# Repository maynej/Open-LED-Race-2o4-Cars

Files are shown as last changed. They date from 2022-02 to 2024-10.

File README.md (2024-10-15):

# OpenLEDrace-2-4-Cars

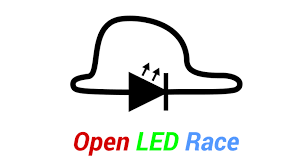
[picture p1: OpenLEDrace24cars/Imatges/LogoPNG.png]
Capses per control, Loop i Bridge per Open LED Race 

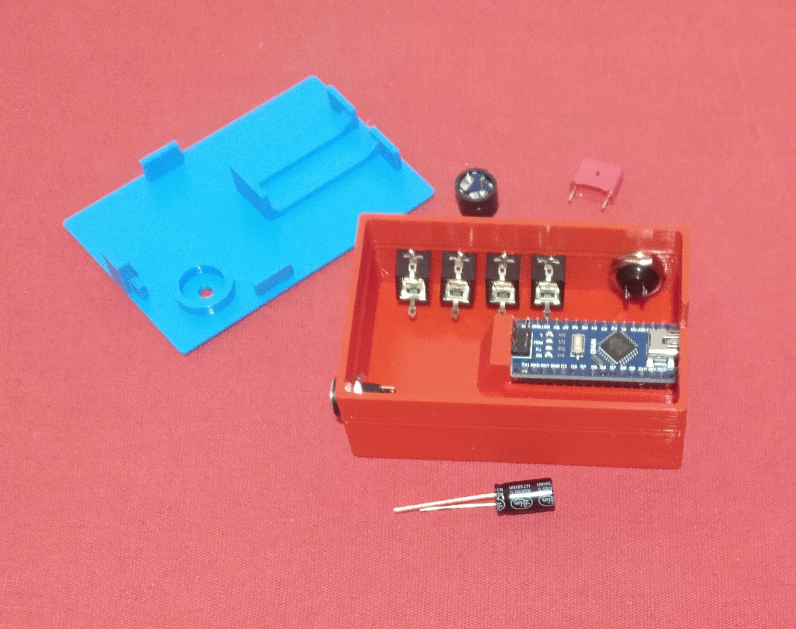
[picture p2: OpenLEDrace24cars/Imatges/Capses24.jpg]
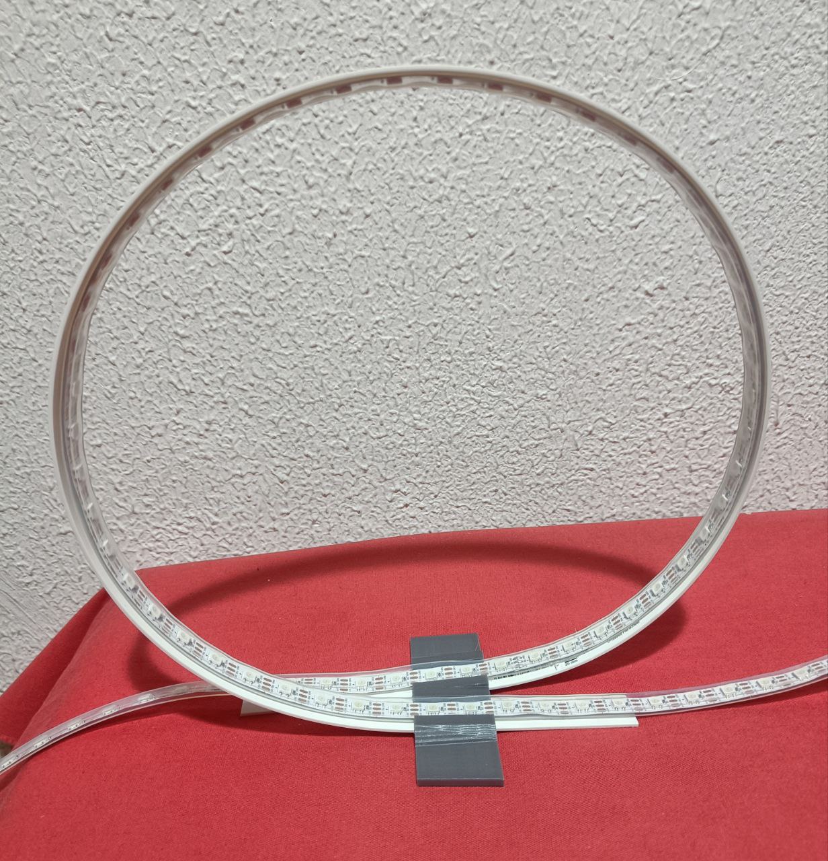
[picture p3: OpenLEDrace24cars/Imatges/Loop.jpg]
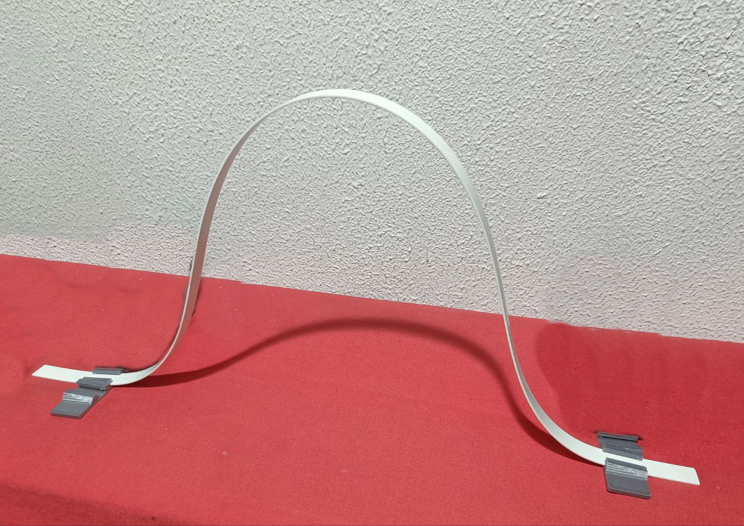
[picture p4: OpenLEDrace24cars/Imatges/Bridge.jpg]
     

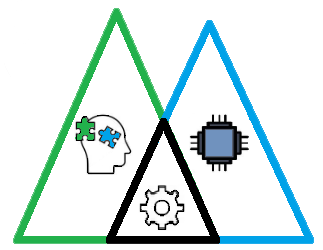
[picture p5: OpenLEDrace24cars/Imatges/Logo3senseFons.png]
Realitzada per [Jordi Mayné](https://github.com/maynej) des de Mechatronic Study 

Web Open LED Race: http://openledrace.net 

L'objectiu es tenir unes capses lleugeres per incloure la placa de control Arduino i el connexionat. També un suport per el Loop.

La [documentació es pot trobar en PDF](https://github.com/maynej/OpenLEDrace24cars/tree/main/OpenLEDrace24cars/DOC). També en llengua castellana.

El Firmware utilitzat [es pot trobar a](https://github.com/maynej/OpenLEDrace24cars/tree/main/OpenLEDrace24cars/Firmware). 

STL per imprimir [aquí](https://github.com/maynej/OpenLEDrace24cars/tree/main/OpenLEDrace24cars/STL).

## Capses 3D 
  
Descripció         | Imatge          | Arxius STL         
------------- | ------------- | ------------- 
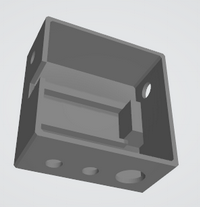
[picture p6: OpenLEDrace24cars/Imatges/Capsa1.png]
Capsa 2/4 jugadors | | [Capsa 2/4 jugadors](OpenLEDrace24cars/STL/CapsaArduinoOpenLedRaceV1.stl)
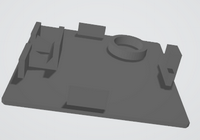
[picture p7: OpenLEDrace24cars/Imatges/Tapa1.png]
Tapa 2/4 jugadors | | [Tapa 2/4 jugadors](OpenLEDrace24cars/STL/TapaArduinoOpenLedRaceV1.stl)
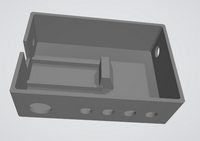
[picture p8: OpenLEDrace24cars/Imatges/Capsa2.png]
Capsa 4 jugadors | | [Capsa 4 jugadors](OpenLEDrace24cars/STL/Capsa_ArduinoGran4Players.stl)
Tapa 4 jugadors | | [Tapa 4 jugadors](OpenLEDrace24cars/STL/TapaArduino4Players.stl)

## Loops & bridges  
  
Descripció         | Imatge          | Arxius STL         
------------- | ------------- | ------------- 
Suport Loop | | [Suport Loop](OpenLEDrace24cars/STL/SuportLoopOLR.stl)
Suport Bridge 1 | | [Suport Bridge 1](OpenLEDrace24cars/STL/SuportBridgeOLR1.stl)
Suport Bridge 2 | | [Suport Bridge 2](OpenLEDrace24cars/STL/SuportBridgeOLR2.stl)

## Polsadors 3D
Descripció         | Imatge          | Arxiu STL          
------------- | ------------- | ------------- 
Polsador ergonomic | | [Polsador ergonomic](OpenLEDrace24cars/STL/OpenLedRace_Handle.stl)

## QR


## Llicència

Creative Commons Attribution-NoComercial-ShareAlike 4.0 International (CC BY-NC-SA 4.0)

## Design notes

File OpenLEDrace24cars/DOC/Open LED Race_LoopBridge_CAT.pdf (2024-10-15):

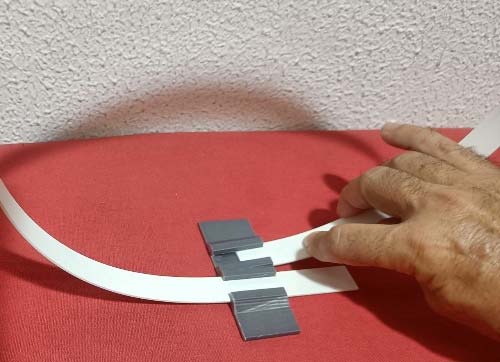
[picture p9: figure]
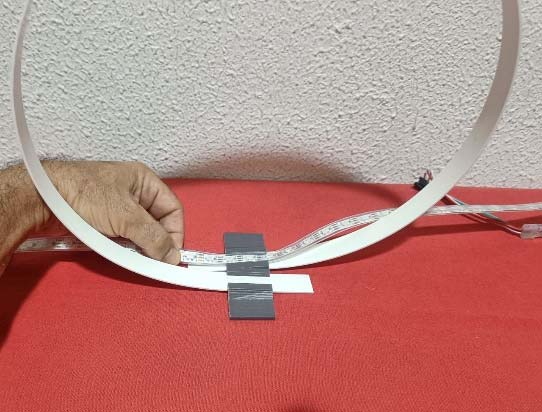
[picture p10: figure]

1

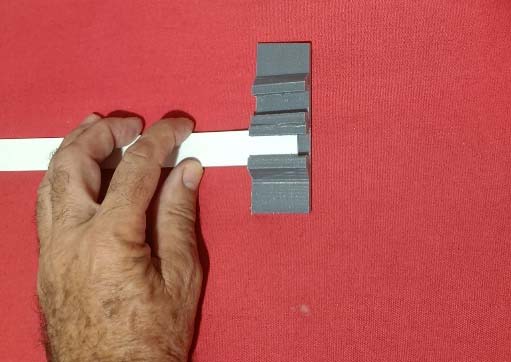
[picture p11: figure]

Jordi Mayné 2024

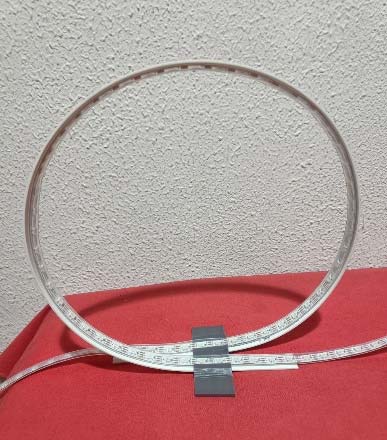
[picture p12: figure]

## Construcció del Loop per Open LED Race

Una de les parts més curioses del joc Open LED Race és la construcció d'un Loop, on depenent del microprogramari hi ha la possibilitat de que el jugador comprovi la força de la gravetat, si el vehicle no porta una velocitat suficient no podrà passar el Loop. Haurà de deixar caure enrere per tornar a agafar l'acceleració necessària per passar aquest Loop.

La dificultat d´aquesta construcció s´ha resolt molt fàcilment amb una platina de PVC i peça impresa en 3D..

Material i montatge:

- 1 Platina de PVC blanc de 20 x 2 x 1000 mm
- 1 Suport de platina i Neopixel

Una vegada imprès el suport s'insereix la platina a través de la ranura i es deixa sortir per l'altra banda, després s'insereix l'altra punta de la platina pel costat contrari i el Loop s'aguantarà ben estable. Depenent de la inserció pot quedar més petit o més gran (uns 25 cm de diàmetre).

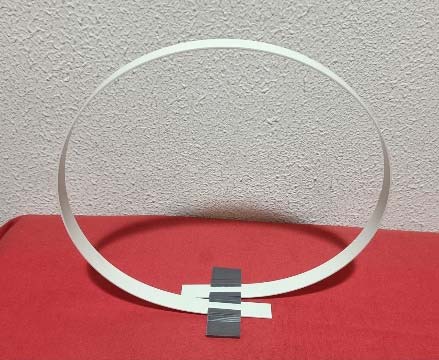
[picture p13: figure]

Ara es prepara la tira de LED Neopixel i es posa en el punt adequat (amb els llums actius de posicionament en la part més alta del Loop), la ranura per la tira Neopixel està molt justa perquè es retingui i no cal posar cap cinta adhesiva, s'aguantará sense cap problema.

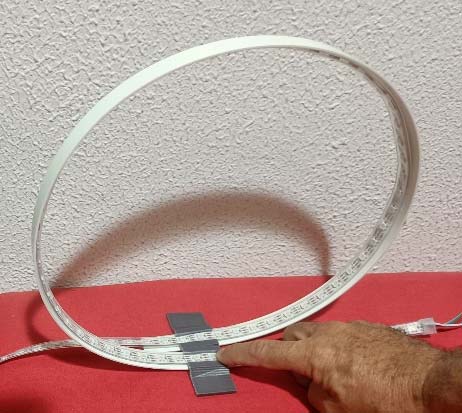
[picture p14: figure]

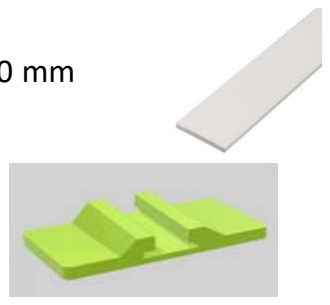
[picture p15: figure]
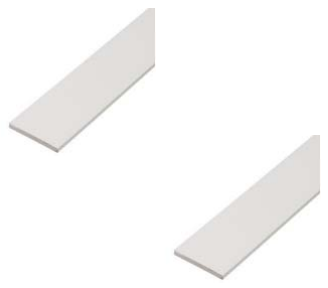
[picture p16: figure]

2
Jordi Mayné 2024

## Construcció del Bridge per Open LED Race

Una alternativa al Loop pot ser un Bridge. Però, també es pot posar en qualsevol part del circuit com un pont.

Aprofitant el disseny de la peça per fer el Loop i fent una mica de modificació s´ha resolt de dues maneres.

Material i muntatge:

- 1 Platina de PVC blanc de 20 x 2 x 1000 mm
- 1 Suport de platina i Neopixel

Aquest muntatge cal afegir cinta adhesiva en el suport.

L’altre solució es amb el suport següent que necessita a més una platina d’alumini de 2 x 20 x L, on L es la longitud, crec que pot anar bé des de 50 cm fins 100 cm segons agradi.

Material i muntatge:

- 1 Platina de PVC blanc de 20 x 2 x 1000 mm
- 1 Platina d’alumini de 20 x 2 x L mm
- 1 Suport de platina i Neopixel

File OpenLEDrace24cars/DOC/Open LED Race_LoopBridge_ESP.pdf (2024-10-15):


1


Jordi Mayné 2024


## Construcción del Loop para Open LED Race

Una de las partes más curiosas del juego Open LED Race es la construcción de un Loop donde dependiendo del firmware hay la posibilidad de que el jugador compruebe la fuerza de la gravedad, si el vehículo no lleva una velocidad adecuada no podrá pasar el Loop. Tendrá que dejar caer hacia atrás para volver a coger la aceleración necesaria para pasar dicho Loop.

La dificultad de esta construcción se ha resuelto muy fácilmente con una pletina de PVC y pieza impresa en 3D.

Material y montaje:

- 1 Pletina de PVC blanco de 20 x 2 x 1000 mm
- 1 Soporte de pletina y Neopixel

Una vez impreso el soporte se inserta la pletina a través de la ranura y se deja salir por el otro lado, después se inserta la otra punta de la pletina por el lado contrario y el Loop se aguantará bien estable. Dependiendo de la inserción puede quedar más pequeño o más grande (unos 25 cm de diámetro).


Ahora se prepara la tira de LED Neopixel y se pone en el punto adecuado (con las luces activas de posicionamiento en la parte más alta del Loop), la ranura para Neopixel está muy justa para que se retenga y no hace falta poner ninguna cinta adhesiva, se aguantará sin ningún problema.


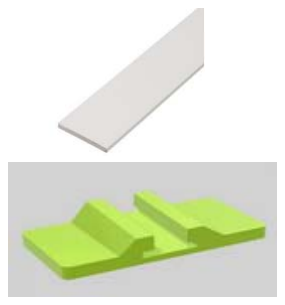
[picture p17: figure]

2
Jordi Mayné 2024

## Construcción del Bridge para Open LED Race

Una alternativa al Loop puede ser un Bridge. Pero también se puede poner en cualquier parte del circuito como un puente.

Aprovechando el diseño de la pieza para hacer el Loop y haciendo una pequeña modificación se ha resuelto de dos maneras.

Material y montaje:

- 1 Pletina de PVC blanco de 20 x 2 x 1000 mm
- 2 Soportes iguales para pletina y Neopixel

Este montaje necesita añadir una cinta adhesiva en el soporte.

Otra solución es con el soporte siguiente, que necesita además una pletina de aluminio de 2 x 20 x L, donde L es la longitud, creo que puede ir bien desde 50 cm hasta 100 cm según agrade.

Material y montaje:

- 1 Pletina de PVC blanco de 20 x 2 x 1000 mm
- 1 Pletina de aluminio de 20 x 2 x L
- 2 Soportes iguales para pletina y Neopixel

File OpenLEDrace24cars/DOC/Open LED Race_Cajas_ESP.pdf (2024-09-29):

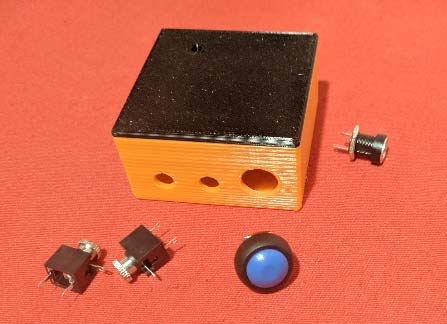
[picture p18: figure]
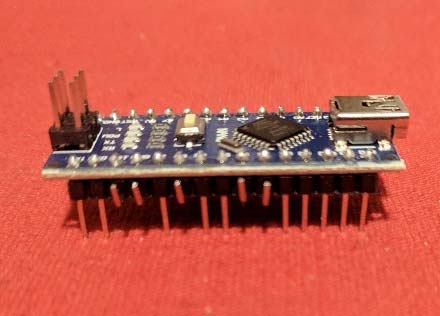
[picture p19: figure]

Jordi Mayné 2020

## Open LED Race 2 jugadores caja pequeña

Material y montaje del Arduino:

- STL de https://www.thingiverse.com/thing:4082216
- 2 jacks hembra 3,5mm PJ-301M
- 1 Pulsador PBS-33b 12mm
- 1 Conector de alimentación hembra de 7,8mm de diámetro
- 1 Condensador electrolítico 1000uF/6V3
- 1 Resistencia entre 330 y 500 ohm
- 1 Zumbador 12 mm
- 1 Condensador 1uF cerámico
- 1 Arduino Nano
- 1 Cable con conector JST de 3 pines macho

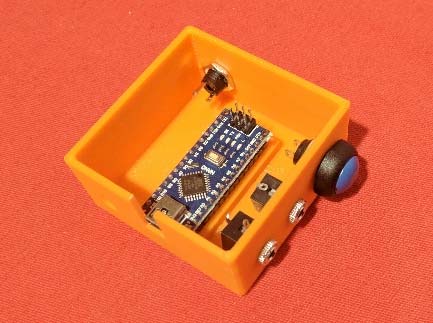
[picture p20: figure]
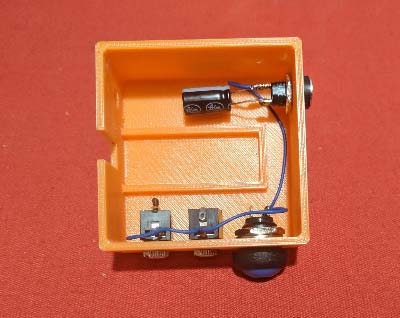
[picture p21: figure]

Una vez montados los conectores y el pulsador, hace falta preparar la placa Arduino. Todos los pines que se han de utilizar hace falta doblar hacia arriba, tal como se muestra en la primera imagen utilizando unos alicates de punta fina, después se estañan, tal como se muestra la segunda imagen y después se sueldan los cables y la resistencia.

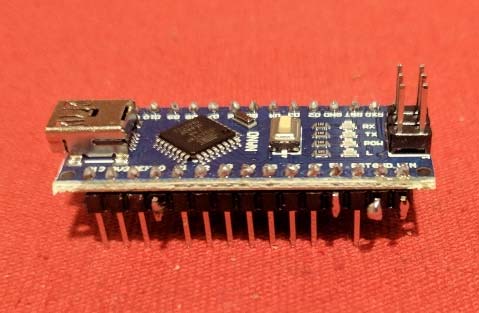
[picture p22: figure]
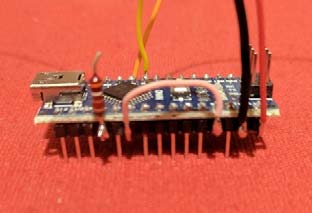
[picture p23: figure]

Se coloca la placa Arduino Nano en el encaje de la caja y se sueldan los hilos a los conectores, y el resto de componentes. Pero se ha de mirar el firmware que se quiere utilizar para mirar la configuración de los pines.

En este caso se ha de utilizar:

- PIN_LED | A0 a R 470 ohms hacia el pin DIN de la tira Neopixel WS2812b
- PIN_P1 | D7 al conector del jugador 1
- PIN_P2 | D6 al conector del jugador 2
- PIN_AUDIO D3 al condensador de 1uF hacia el zumbador
- Alimentación VIN a +5V GND a massa
- Puente entre A2 y 5V
- RST al pulsador de Reset

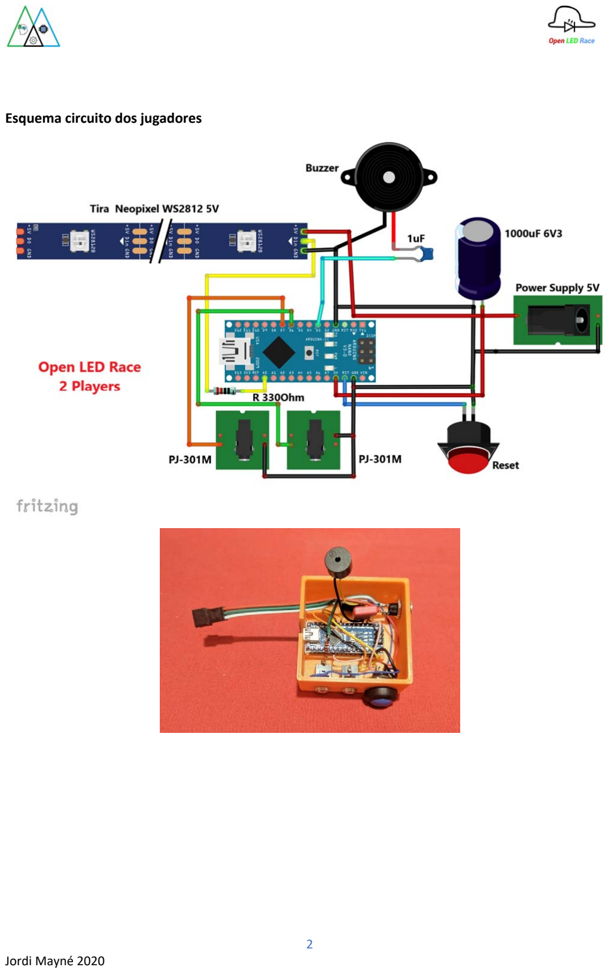
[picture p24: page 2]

Esquema circuito dos jugadores

Materiales y montaje de los pulsadores:

- STL de https://www.thingiverse.com/thing:3645054
- Un cable coaxial o de dos hilos
- Botón Arcade tipo Sanwa de 24mm
- Jack 3,5mm macho de dos polos

Es pasa el cable por el agujero inferior del soporte, se hace un nudo a una distancia para que quede trabado en caso de haber un tirón del cable y se rompa la conexión. Se pela la punta del hilo, se estaña y se suelda al botón. Se coloca el botón en el soporte y solo queda en la otra punta del cable soldar el jack macho.

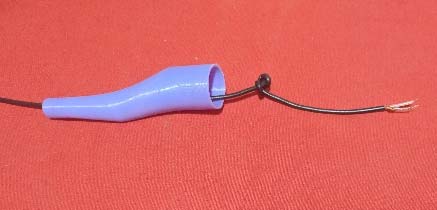
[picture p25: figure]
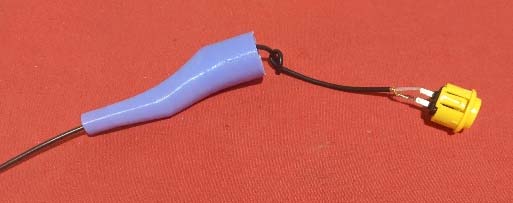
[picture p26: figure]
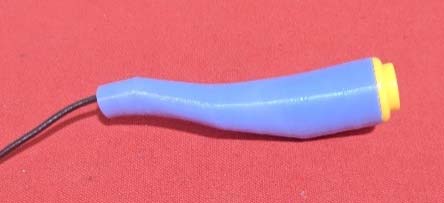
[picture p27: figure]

Hay muchos tipos de pulsadores diseñados en www.thingiverse.com , se puede buscar el que más agrade.

De soportes de pulsadores hay diferentes versiones, que también se pueden utilizar, solo hay que tener en cuenta el diámetro del pulsador, por ejemplo este para sobremesa de 30mm:

https://www.thingiverse.com/thing:4161781

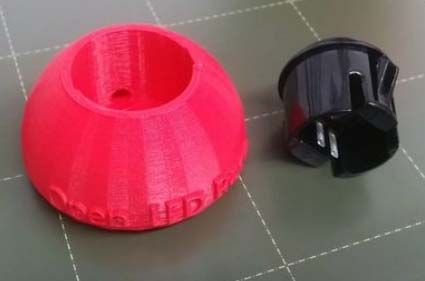
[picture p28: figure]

O este más ergonómico https://www.thingiverse.com/thing:4764958

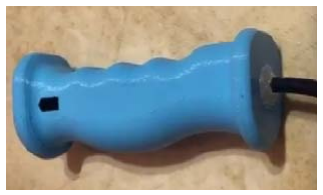
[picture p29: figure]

## Open LED Race 4 jugadores caja pequeña

Si se quiere utilizar la misma caja pero con 4 jugadores es relativamente sencillo, hace falta pone otro tipo de conectores jack hembra, el modelo estéreo PJ-324M y un jack macho que se conectará a dos cables de extensión jack hembra de 3,5mm y dos hilos cada uno, cambiando el conexionado de algunos pines del Arduino.

Material y montaje del Arduino:

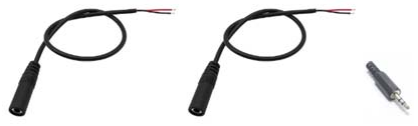
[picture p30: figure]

- STL de https://www.thingiverse.com/thing:4082216
- 2 jacks hembra 3,5mm PJ-324M
- 1 Pulsador PBS-33b 12mm
- 1 Conector de alimentación hembra de 7,8mm de diámetro
- 1 Condensador electrolítico 1000uF/6V3
- 1 Resistencia entre 330 y 500 ohm
- 1 Zumbador 12 mm
- 1 Condensador 1uF cerámico
- 1 Arduino Nano
- 1 Cable con conector JST de 3 pines macho

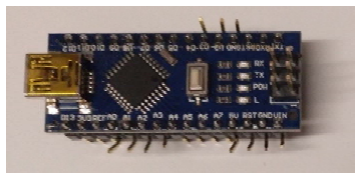
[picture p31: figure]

Preparar la placa de Arduino Nano. Todos los pines que se han de utilizar, se doblan hacia arriba, tal como se muestra en esta imagen, utilizando unos alicates de punta fina, después se estañan y se sueldan los cables y la resistencia.

En aquest cas se utilizan:

- PIN_LED D2 a R 500 ohms hacia el pin DIN del WS2812
- DIG_CONTROL_1 A0 al pin del conector 2 de PJ-324M1
- DIG_CONTROL_2 A1 al pin del conector 5 de PJ-324M1
- DIG_CONTROL_3 A2 al pin del conector 2 de PJ-324M2
- DIG_CONTROL_4 A3 al pin del conector 5 de PJ-324M2
- PIN_AUDIO D3 al condensador de 1uF hacia el zumbador
- Alimentación VIN a +5V GND a massa
- RST al pulsador de Reset

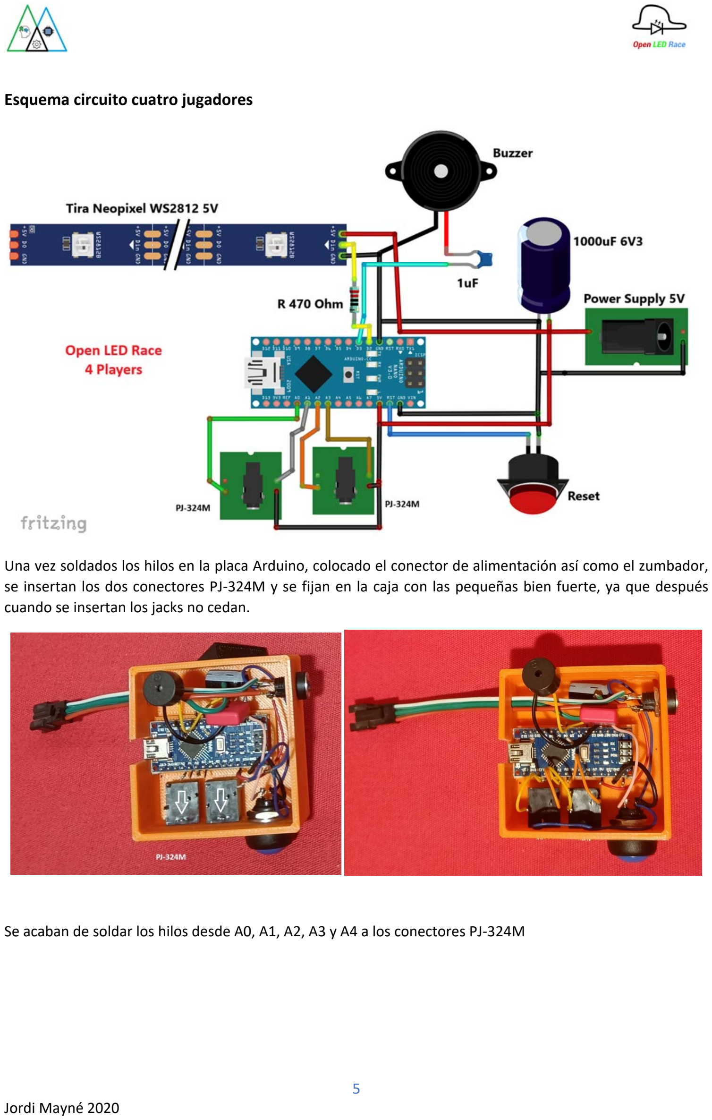
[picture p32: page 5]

Esquema circuito cuatro jugadores

Una vez soldados los hilos en la placa Arduino, colocado el conector de alimentación así como el zumbador, se insertan los dos conectores PJ-324M y se fijan en la caja con las pequeñas bien fuerte, ya que después cuando se insertan los jacks no cedan.

Se acaban de soldar los hilos desde A0, A1, A2, A3 y A4 a los conectores PJ-324M

### Preparación de los cables de extensión


Los pulsadores se utilizan los mismos que en las otras versiones de caja tal como antes se ha descrito.

## Open LED Race 4 jugadores caja grande

Material y montaje del Arduino:

- STL de https://www.thingiverse.com/thing:4082216
- 4 jacks hembra de 3,5mm PJ-301M
- 1 Pulsador PBS-33b 12mm
- 1 Conector de alimentación hembra de 7,8mm de diámetro
- 1 Condensador electrolítico 1000uF/
- 1 Resistencia entre 330 i 500 ohm
- 1 Zumbador 12 mm
- 1 Condensador 1uF cerámico
- 1 Arduino Nano
- 1 Cable con conector JST de 3 pines macho


Primero, colocar los conectores de pulsadores, alimentación y el botón de reset. Hacer las conexiones correspondientes.


Preparar la placa de Arduino Nano. Todos los pines que se han de utilizar, se doblan hacia arriba, tal como se muestra en esta imagen, utilizando unos alicates de punta fina, después se estañan y se sueldan los cables y la resistencia.


En este caso se utilizan:

- PIN_LED D2 a R 500 ohms hacia el pin DIN del WS2812
- DIG_CONTROL_1 A2 al conector jugador 1
- DIG_CONTROL_2 A0 al conector jugador 2
- DIG_CONTROL_3 A3 al conector jugador 3
- DIG_CONTROL_4 A1 al conector jugador 4
- PIN_AUDIO D3 al condensador de 1uF hacia el zumbador
- Alimentación VIN a +5V GND a massa
- RST al pulsador de Reset
•

Los pulsadores se utilizan los mismos que en las otras versiones de caja tal como antes se ha descrito.

Recursos y firmware en la web de Open LED race: https://openledrace.net/1679-2/?lang=es

Tutoriales: https://openledrace.net/tutoriales/?lang=es

Youtube: Open LED race

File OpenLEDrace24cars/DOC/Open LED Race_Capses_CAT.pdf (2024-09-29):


Jordi Mayné 2020

## Open LED Race 2 jugadors capsa petita

Material i muntatge del Arduino:

- STL de https://www.thingiverse.com/thing:4082216
- 2 jacks femelles 3,5mm PJ-301M
- 1 Polsador PBS-33b 12mm
- 1 Connector d’alimentació femella de 7,8mm de diàmetre
- 1 Condensador electrolític 1000uF/6V3
- 1 Resistència entre 330 i 500 ohm
- 1 Brunzidor 12 mm
- 1 Condensador 1uF ceràmic
- 1 Arduino Nano
- 1 Cable amb connector JST de 3 pins mascle


Una vegada muntats els connectors i el polsador, cal preparar la placa Arduino. Tots els pins que s’han d’utilitzar cal doblegar cap amunt, tal com es mostra a la primera imatge utilitzant unes alicates de punta fina, desprès s’estanyen, tal com es mostra la segona imatge i desprès es solden els cables i la resistència.


Es col.loca la placa Arduino Nano en el encaix de la capsa i es solden el fils als connectors, i resta de components. Però, s’ha de mirar el firmware que es vol fer servir per mirar la configuració de pins.

En aquest cas es fa servir:

- PIN_LED | A0 a R 470 ohms cap la pin DIN de la tira Neopixel WS2812b
- PIN_P1 | D7 al connector del jugador 1
- PIN_P2 | D6 al connector del jugador 2
- PIN_AUDIO D3 al condensador de 1uF cap al brunzidor
- Alimentació VIN a +5V GND a massa
- Pont entre A2 i 5V
- RST al polsador de Reset


Esquema circuit de dos jugadors

Materials i muntatge del polsadors:

- STL de https://www.thingiverse.com/thing:3645054
- Un cable coaxial o de dos fils
- Botó Arcade tipus Sanwa de 24mm
- Jack 3,5mm mascle de dos pols

Es passa el cable per el forat inferior del suport, es fa un nus a una distància perquè quedi travat en cas de fer un estirada del cable i es trenqui la connexió. Es pela la punta del fil, s’estanya i es solda en el botó. Es col·loca el botó en el suport i només queda en el altre punta del cable soldar el jack mascle.


Hi ha molts tipus de polsadors dissenyats, a www.thingiverse.com es pot buscar el que més agradi.

Del polsadors hi ha diferents versions, que també es poden fer servir, només cal tenir en compte el diàmetre del posador, per exemple aquest per sobretaula es de 30mm: https://www.thingiverse.com/thing:4161781


O aquest ergonòmic https://www.thingiverse.com/thing:4764958


## Open LED Race 4 jugadors capsa petita

Si es vol utilitzar la mateixa capsa però, posar 4 jugadors es relativament senzill, cal posar un altre tipus de connectors jack femella, el model estèreo PJ-324M i un jack mascle que es connectarà a dos cables d’extensió jack femella de 3,5mm de dos fils cada un i canviar el connexionat d’alguns pins de Arduino.

Material i muntatge del Arduino:


- STL de https://www.thingiverse.com/thing:4082216
- 2 jacks femelles 3,5mm PJ-324M
- 1 Polsador PBS-33b 12mm
- 1 Connector d’alimentació femella de 7,8mm de diàmetre
- 1 Condensador electrolític 1000uF/
- 1 Resistència entre 330 i 500 ohm
- 1 Brunzidor 12 mm
- 1 Condensador 1uF ceràmic
- 1 Arduino Nano
- 1 Cable amb connector JST de 3 pins mascle


Preparar la placa de Arduino Nano. Tots els pins que s’han d’utilitzar cal doblegar cap amunt, tal com es mostra a la primera imatge utilitzant unes alicates de punta fina, desprès s’estanyen i es solden els cables i la resistència.

En aquest cas es fa servir:

- PIN_LED D2 a R 500 ohms cap la pin DIN del WS2812
- DIG_CONTROL_1 A0 al pin del connector 2 de PJ-324M1
- DIG_CONTROL_2 A1 al pin del connector 5 de PJ-324M1
- DIG_CONTROL_3 A2 al pin del connector 2 de PJ-324M2
- DIG_CONTROL_4 A3 al pin del connector 5 de PJ-324M2
- PIN_AUDIO D3 al condensador de 1uF cap al brunzidor
- Alimentació VIN a +5V GND a massa
- RST al polsador de Reset


Esquema circuit de quatre jugadors

Una vegada soldats els fils en la placa Arduino, col·locat el connector d’alimentació així com el brunzidor, s’insereixen els dos connectors PJ-324M i es fixen a la capsa amb les petites femelles ben fort, ja que desprès quan s’insereixin els jacks no cedeixin.

S’acaben de soldar els fils des de A0, A1, A2, A3 i A4 als connectors PJ-324M

### Preparació dels cables d’extensió


Els polsadors es fan servir els mateixos que en les altres versions de capsa, tal com abans s’ha descrit.

## Open LED Race 4 jugadors capsa gran

Material i muntatge del Arduino:

- STL de https://www.thingiverse.com/thing:4082216
- 4 jacks femelles 3,5mm PJ-301M
- 1 Polsador PBS-33b 12mm
- 1 Connector d’alimentació femella de 7,8mm de diàmetre
- 1 Condensador electrolític 1000uF/
- 1 Resistència entre 330 i 500 ohm
- 1 Brunzidor 12 mm
- 1 Condensador 1uF ceràmic
- 1 Arduino Nano
- 1 Cable amb connector JST de 3 pins mascle


Primer col·locar els connectors de polsadors, alimentació i el botó de reset. Fer les connexions corresponents.


Preparar la placa de Arduino Nano. Tots els pins que s’han d’utilitzar cal doblegar cap amunt, tal com es mostra a la primera imatge utilitzant unes alicates de punta fina, desprès s’estanyen i es solden els cables i la resistència.


En aquest cas es fa servir:

- PIN_LED D2 a R 500 ohms cap la pin DIN del WS2812
- DIG_CONTROL_1 A2 al connector jugador 1
- DIG_CONTROL_2 A0 al connector jugador 2
- DIG_CONTROL_3 A3 al connector jugador 3
- DIG_CONTROL_4 A1 al connector jugador 4
- PIN_AUDIO D3 al condensador de 1uF cap al brunzidor
- Alimentació VIN a +5V GND a massa
- RST al polsador de Reset

Els polsadors es fan servir els mateixos que en les altres versions de capsa, tal com abans s’ha descrit.

Recursos i firmware a la web de Open LED race: https://openledrace.net/1679-2/?lang=es

Tutorials: https://openledrace.net/tutoriales/?lang=es

Youtube: Open LED race

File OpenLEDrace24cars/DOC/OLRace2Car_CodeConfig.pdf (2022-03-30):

# Codi de Open Led Race

#include <Adafruit_NeoPixel.h> Crida a la llibreria de NeoPixel

#define MAXLED | 300 // Número de LEDs actius en la tira

#define PIN_LED | A0 // Pin Dades a pin DI de WS2812i WS2813, per WS2813 BI pin de primer LED

a GND, CAP 1000 uF a VCC 5v/GND, alimentació 5V 2A
#define PIN_P1 | 7 // Pin Polsador 1

#define PIN_P2 | 6 // Pin Polsador 2

#define PIN_AUDIO 3 // Pin Audio a través de Condensador 2uf al altaveu o brunzidor.

#define COLOR1 track.Color(255,0,255)


línia 41 presenta la música que tocarà al final de la carrera en la línia 136 tone(PIN_AUDIO, win_music[note],200);
int win_music[] = {
2637, 2637, 0, 2637, 0, 2093, 2637, 0, 3136
2637 es un Mi 7a octava, 2093 es un Do 7a octava, 3136 es un Sol 7a octava

Pots veure en aquesta pàgina com van les notes musicals i les freqüències https://juegosrobotica.es/musica-con-arduino/#

Saltem a la línia 60
byte loop_max=5; //total laps race en aquest cas programat a 5 voltes.

Saltem a la línia 64 i 65
float kf=0.015; //friction constant coeficient de fricció float kg=0.003; //gravity constant coeficient de gravetat

Saltem a la línia 96
if ((digitalRead(PIN_P1)==0)) //push switch 1 on reset for activate physic Polsant SW1+Reset per activar la gravetat

Saltem a la línia 98
set_ramp(12,90,100,110); // ramp centred in LED 100 with 10 led fordward and 10 backguard El centre de la zona de més alta gravetat està en el LED 100 i 10 per cada banda.

Saltem a la línia 102
start_race(); Comença la carrera

Saltem a la línia 108 - 109
track.setPixelColor(12, track.Color(0,255,0)); Verd LED 12
track.setPixelColor(11, track.Color(0,255,0)); | Verd LED 11
Saltem a la línia 111 a 113 | Primer só
tone(PIN_AUDIO,400); | Sol 4a octava
delay(2000); | Toca durant 2 segons (nota blanca)
noTone(PIN_AUDIO); | Para l’àudio
track.setPixelColor(12, track.Color(0,0,0)); | LED 12 Apagat
track.setPixelColor(11, track.Color(0,0,0)); | LED 11 Apagat
track.setPixelColor(10, track.Color(255,255,0)); LED 10 Groc track.setPixelColor(9, track.Color(255,255,0)); LED 9 Groc

Saltem a la línia 119 a 121 Segon so
tone(PIN_AUDIO,600); | Re 5a octava
delay(2000); | Toca durant 2 segons (nota blanca)
noTone(PIN_AUDIO); | Para l’àudio

Saltem a la línia 119 a 121
track.setPixelColor(9, track.Color(0,0,0)); | LED 9 Apagat
track.setPixelColor(10, track.Color(0,0,0)); | LED 10 Apagat
track.setPixelColor(8, track.Color(255,0,0)); | LED 8 Vermell
track.setPixelColor(7, track.Color(255,0,0)); | LED 7 Vermell

Saltem a la línia 127 a 129 Tercer so
tone(PIN_AUDIO,1200); | Re 6a octava
delay(2000); | Toca durant 2 segons (nota blanca)
noTone(PIN_AUDIO); | Para l’àudio
Saltem a la línia 136 a 138 | So de Sortida
tone(PIN_AUDIO, win_music[note],200); Sol 3a octava
delay(230); | Toca durant 2 segons (nota semicorxera)
noTone(PIN_AUDIO); | Para l’àudio
Saltem a la línia 246 a 247 | Càlcul velocitat SW1
if ( (flag_sw1==1) && (digitalRead(PIN_P1)==0) ) {flag_sw1=0;speed1+=ACEL;}; if ( (flag_sw1==0) && (digitalRead(PIN_P1)==1) ) {flag_sw1=1;};

Saltem a la línia 246 a 247 Càlcul velocitat SW2
if ( (flag_sw2==1) && (digitalRead(PIN_P2)==0) ) {flag_sw2=0;speed2+=ACEL;}; if ( (flag_sw2==0) && (digitalRead(PIN_P2)==1) ) {flag_sw2=1;};
Saltem a la línia 269 a 270
if (dist1>NPIXELS*loop1) {loop1++;tone(PIN_AUDIO,600);TBEEP=2;}; Re 5a octava if (dist2>NPIXELS*loop2) {loop2++;tone(PIN_AUDIO,700);TBEEP=2;}; Fa 5a octava

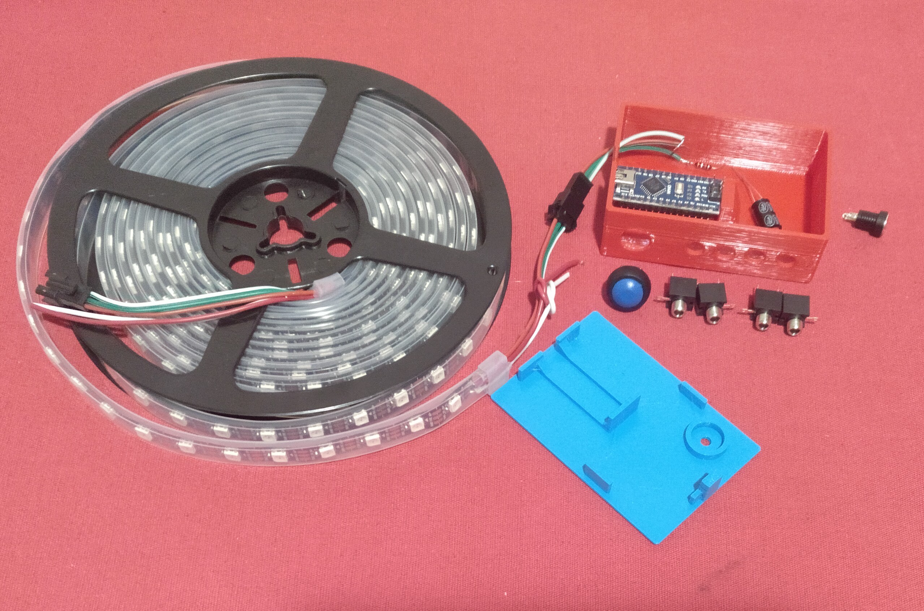
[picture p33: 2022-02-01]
OpenLEDrace24cars/Imatges/OpenLedRace4Cars.jpg

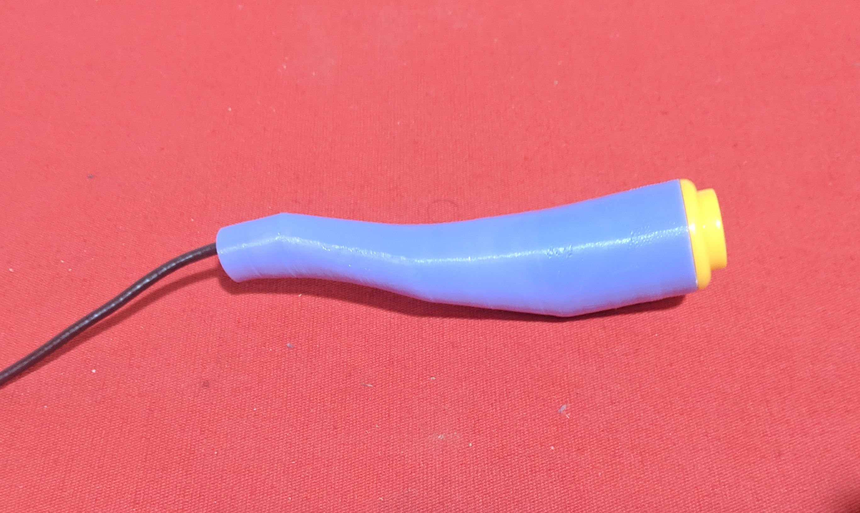
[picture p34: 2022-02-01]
OpenLEDrace24cars/Imatges/OpenLedRacePolsador.jpg

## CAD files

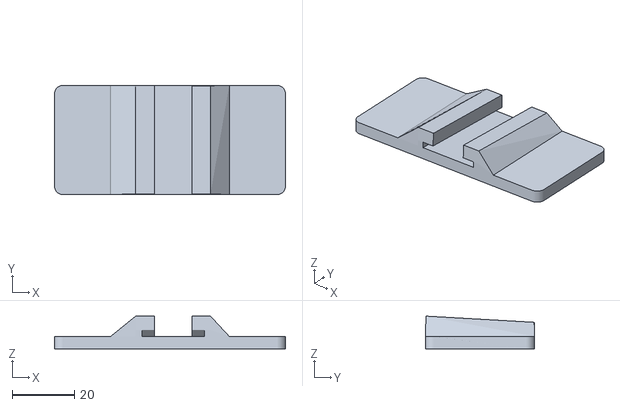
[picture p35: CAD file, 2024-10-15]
OpenLEDrace24cars/STL/SuportBridgeOLR1.stl
74.0 x 35.0 x 10.5

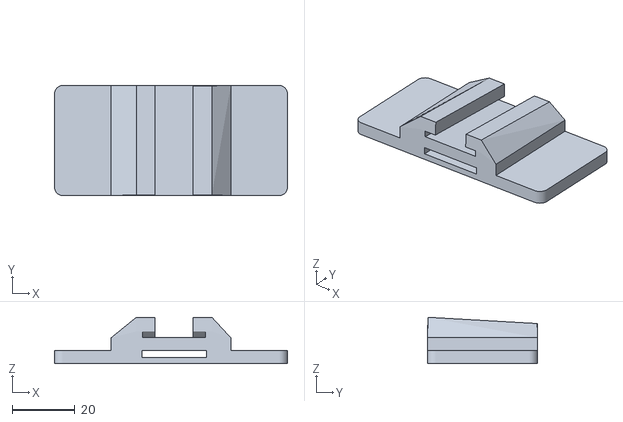
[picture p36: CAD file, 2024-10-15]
OpenLEDrace24cars/STL/SuportBridgeOLR2.stl
74.0 x 35.0 x 14.7

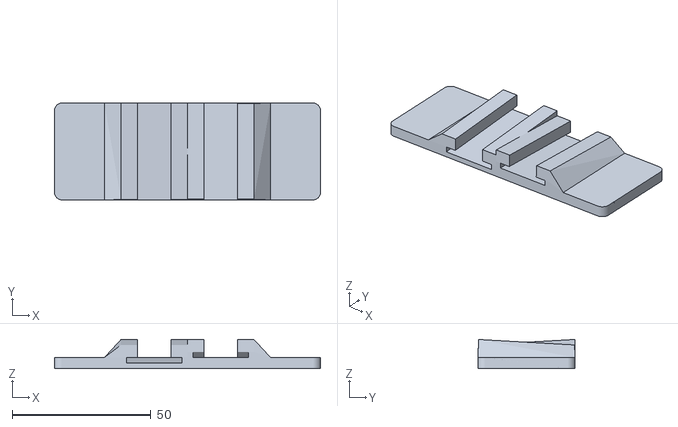
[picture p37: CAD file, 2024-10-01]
OpenLEDrace24cars/STL/SuportLoopOLR.stl
96.0 x 35.0 x 10.5

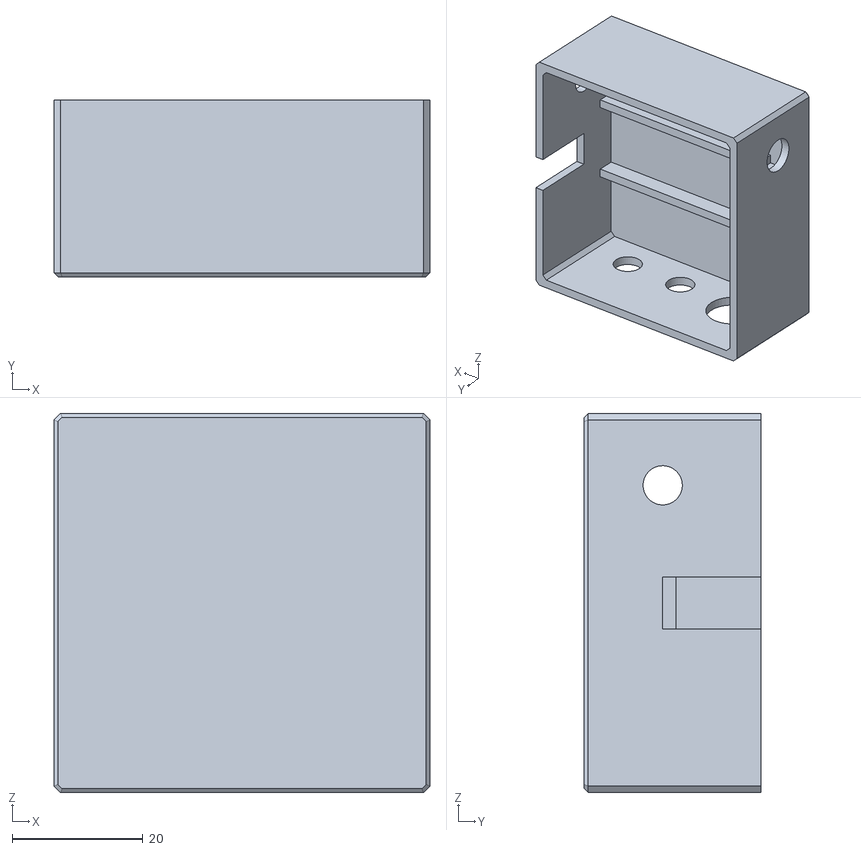
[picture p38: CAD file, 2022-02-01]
OpenLEDrace24cars/STL/CapsaArduinoOpenLedRaceV1.stl
57.5 x 27.0 x 58.0

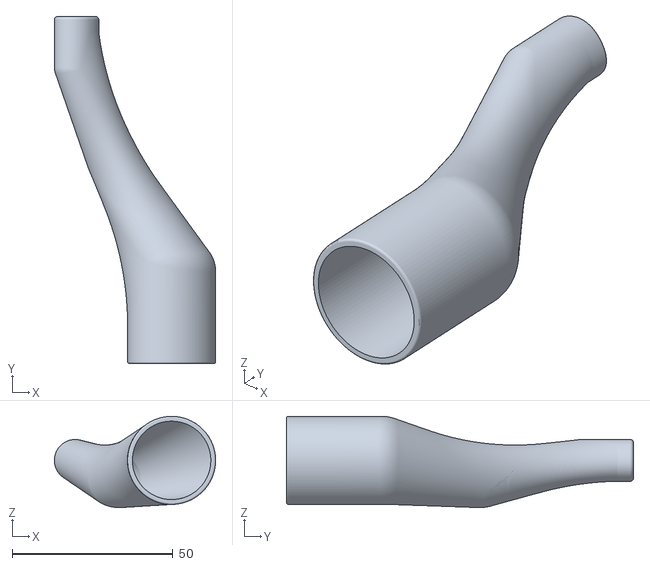
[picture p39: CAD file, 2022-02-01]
OpenLEDrace24cars/STL/OpenLedRace_Handle.stl
50.2 x 108.0 x 28.4

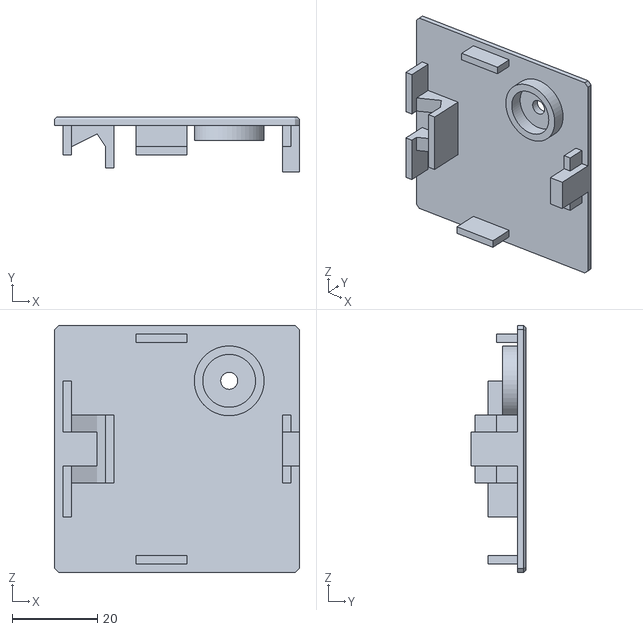
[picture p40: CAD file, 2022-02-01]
OpenLEDrace24cars/STL/TapaArduinoOpenLedRaceV1.stl
57.5 x 13.0 x 58.0

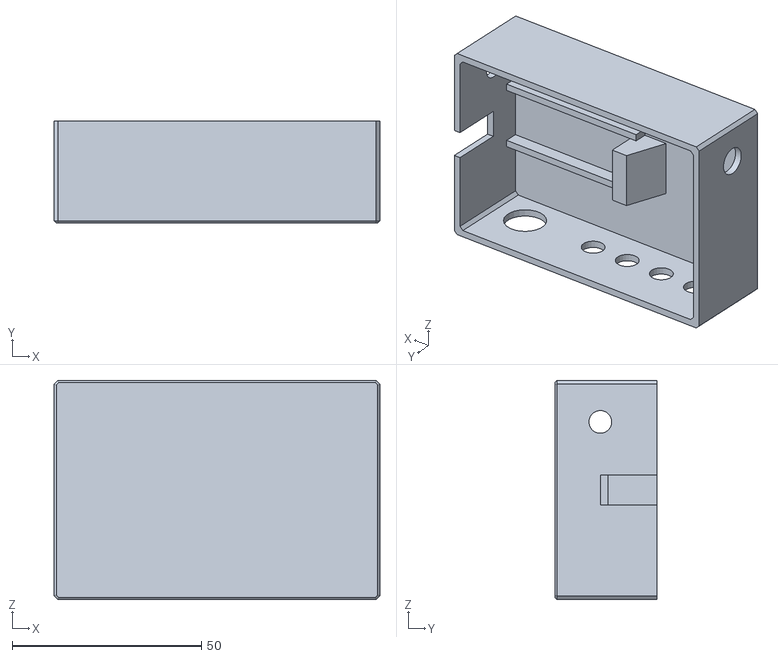
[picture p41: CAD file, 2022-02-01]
OpenLEDrace24cars/STL/Capsa_ArduinoGran4Players.stl
86.2 x 27.0 x 58.0

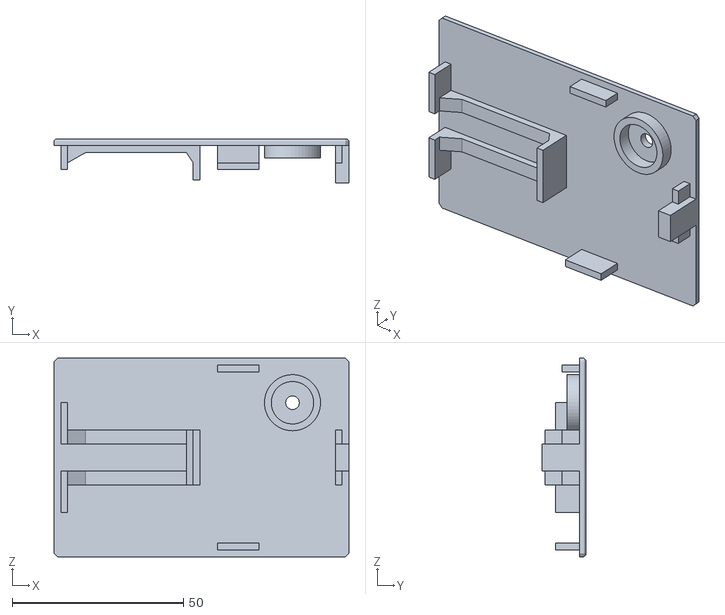
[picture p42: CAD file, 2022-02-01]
OpenLEDrace24cars/STL/TapaArduino4Players.stl
86.2 x 13.0 x 58.0

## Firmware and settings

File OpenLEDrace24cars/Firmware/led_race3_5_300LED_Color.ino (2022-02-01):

/*  
 * ____                     _      ______ _____    _____
  / __ \                   | |    |  ____|  __ \  |  __ \               
 | |  | |_ __   ___ _ __   | |    | |__  | |  | | | |__) |__ _  ___ ___ 
 | |  | | '_ \ / _ \ '_ \  | |    |  __| | |  | | |  _  // _` |/ __/ _ \
 | |__| | |_) |  __/ | | | | |____| |____| |__| | | | \ \ (_| | (_|  __/
  \____/| .__/ \___|_| |_| |______|______|_____/  |_|  \_\__,_|\___\___|
        | |                                                             
        |_|          
 Open LED Race
 An minimalist cars race for LED strip  
  
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
 by gbarbarov@singulardevices.com  for Arduino day Seville 2019 

 Code made dirty and fast, next improvements in: 
 https://github.com/gbarbarov/led-race
 https://www.hackster.io/gbarbarov/open-led-race-a0331a
 https://twitter.com/openledrace
*/

                                                            
#include <Adafruit_NeoPixel.h>
#define MAXLED         300 // MAX LEDs actives on strip

#define PIN_LED        A0  // R 500 ohms to DI pin for WS2812 and WS2813, for WS2813 BI pin of first LED to GND  ,  CAP 1000 uF to VCC 5v/GND,power supplie 5V 2A  
#define PIN_P1         7   // switch player 1 to PIN and GND
#define PIN_P2         6   // switch player 2 to PIN and GND 
#define PIN_AUDIO      3   // through CAP 2uf to speaker 8 ohms


int NPIXELS=MAXLED; // leds on track

#define COLOR1    track.Color(255,255,0)    // Groc
#define COLOR2    track.Color(255,0,255,)   // Rosa

int win_music[] = {
  2637, 2637, 0, 2637, 
  0, 2093, 2637, 0,
  3136    
};
      
byte  gravity_map[MAXLED];     

int TBEEP=3; 

float speed1=0;
float speed2=0;
float dist1=0;
float dist2=0;

byte loop1=0;
byte loop2=0;

byte leader=0;
byte loop_max=5; //total laps race


float ACEL=0.2;
float kf=0.015; //friction constant
float kg=0.003; //gravity constant

byte flag_sw1=0;
byte flag_sw2=0;
byte draworder=0;
 
unsigned long timestamp=0;

Adafruit_NeoPixel track = Adafruit_NeoPixel(MAXLED, PIN_LED, NEO_GRB + NEO_KHZ800);

int tdelay = 5; 

void set_ramp(byte H,byte a,byte b,byte c)
{for(int i=0;i<(b-a);i++){gravity_map[a+i]=127-i*((float)H/(b-a));};
 gravity_map[b]=127; 
 for(int i=0;i<(c-b);i++){gravity_map[b+i+1]=127+H-i*((float)H/(c-b));};
}

void set_loop(byte H,byte a,byte b,byte c)
{for(int i=0;i<(b-a);i++){gravity_map[a+i]=127-i*((float)H/(b-a));};
 gravity_map[b]=255; 
 for(int i=0;i<(c-b);i++){gravity_map[b+i+1]=127+H-i*((float)H/(c-b));};
}


void setup() {
  for(int i=0;i<NPIXELS;i++){gravity_map[i]=127;};
  track.begin(); 
  pinMode(PIN_P1,INPUT_PULLUP); 
  pinMode(PIN_P2,INPUT_PULLUP);  

  if ((digitalRead(PIN_P1)==0)) //push switch 1 on reset for activate physic
  {
    set_ramp(12,90,100,110);    // ramp centred in LED 100 with 10 led fordward and 10 backguard 
    for(int i=0;i<NPIXELS;i++){track.setPixelColor(i, track.Color(0,0,(127-gravity_map[i])/8) );};
    track.show();
  };
  start_race();    
}

void start_race(){for(int i=0;i<NPIXELS;i++){track.setPixelColor(i, track.Color(0,0,0));};
                  track.show();
                  delay(2000);
                  track.setPixelColor(12, track.Color(0,255,0));
                  track.setPixelColor(11, track.Color(0,255,0));
                  track.show();
                  tone(PIN_AUDIO,400);
                  delay(2000);
                  noTone(PIN_AUDIO);                  
                  track.setPixelColor(12, track.Color(0,0,0));
                  track.setPixelColor(11, track.Color(0,0,0));
                  track.setPixelColor(10, track.Color(255,255,0));
                  track.setPixelColor(9, track.Color(255,255,0));
                  track.show();
                  tone(PIN_AUDIO,600);
                  delay(2000);
                  noTone(PIN_AUDIO);                  
                  track.setPixelColor(9, track.Color(0,0,0));
                  track.setPixelColor(10, track.Color(0,0,0));
                  track.setPixelColor(8, track.Color(255,0,0));
                  track.setPixelColor(7, track.Color(255,0,0));
                  track.show();
                  tone(PIN_AUDIO,1200);
                  delay(2000);
                  noTone(PIN_AUDIO);                               
                  timestamp=0;              
                 };

void winner_fx() {
               int msize = sizeof(win_music) / sizeof(int);
               for (int note = 0; note < msize; note++) {
               tone(PIN_AUDIO, win_music[note],200);
               delay(230);
               noTone(PIN_AUDIO);

}

                                               
              };

void burning1(){
//to do
 }

void burning2(){
//to do
 }

void track_rain_fx(){
//to do
 }

void track_oil_fx(){
//to do
 }

void track_snow_fx(){
//to do
 }


void fuel_empty(){
//to do
 }

void fill_fuel_fx(){
//to do
 }

void in_track_boxs_fx(){
//to do
 }

void pause_track_boxs_fx(){
//to do
 }
 
void flag_boxs_stop(){
//to do
 }

void flag_boxs_ready(){
//to do
 }

void draw_safety_car(){
//to do
 }

void telemetry_rx(){
  //to do
 }
 
void telemetry_tx(){
  //to do
 }

void telemetry_lap_time_car1(){
//to do
 }

void telemetry_lap_time_car2(){
//to do
 }

void telemetry_record_lap(){
//to do
 }

void telemetry_total_time(){
//to do
 }

int read_sensor(byte player){
//to do
}

int calibration_sensor(byte player){
  //to do  
}

int display_lcd_laps(){
  //to do  
}

int display_lcd_time(){
  //to do  
}



void draw_car1(void){for(int i=0;i<=loop1;i++){track.setPixelColor(((word)dist1 % NPIXELS)+i, track.Color(0,255-i*20,0));};                   
  }

void draw_car2(void){for(int i=0;i<=loop2;i++){track.setPixelColor(((word)dist2 % NPIXELS)+i, track.Color(255-i*20,0,0));};            
 }
  
void loop() {
    //for(int i=0;i<NPIXELS;i++){track.setPixelColor(i, track.Color(0,0,0));};
    for(int i=0;i<NPIXELS;i++){track.setPixelColor(i, track.Color(0,0,(127-gravity_map[i])/8) );};
    
    if ( (flag_sw1==1) && (digitalRead(PIN_P1)==0) ) {flag_sw1=0;speed1+=ACEL;};
    if ( (flag_sw1==0) && (digitalRead(PIN_P1)==1) ) {flag_sw1=1;};

    if ((gravity_map[(word)dist1 % NPIXELS])<127) speed1-=kg*(127-(gravity_map[(word)dist1 % NPIXELS]));
    if ((gravity_map[(word)dist1 % NPIXELS])>127) speed1+=kg*((gravity_map[(word)dist1 % NPIXELS])-127);
    
    
    speed1-=speed1*kf; 
    
    if ( (flag_sw2==1) && (digitalRead(PIN_P2)==0) ) {flag_sw2=0;speed2+=ACEL;};
    if ( (flag_sw2==0) && (digitalRead(PIN_P2)==1) ) {flag_sw2=1;};

    if ((gravity_map[(word)dist2 % NPIXELS])<127) speed2-=kg*(127-(gravity_map[(word)dist2 % NPIXELS]));
    if ((gravity_map[(word)dist2 % NPIXELS])>127) speed2+=kg*((gravity_map[(word)dist2 % NPIXELS])-127);
        
    speed2-=speed2*kf; 
        
    dist1+=speed1;
    dist2+=speed2;

    if (dist1>dist2) {leader=1;} 
    if (dist2>dist1) {leader=2;};
      
    if (dist1>NPIXELS*loop1) {loop1++;tone(PIN_AUDIO,600);TBEEP=2;};
    if (dist2>NPIXELS*loop2) {loop2++;tone(PIN_AUDIO,700);TBEEP=2;};

    if (loop1>loop_max) {for(int i=0;i<NPIXELS;i++){track.setPixelColor(i, track.Color(0,255,0));}; track.show();
                                                    winner_fx();loop1=0;loop2=0;dist1=0;dist2=0;speed1=0;speed2=0;timestamp=0;
                                                    start_race();
                                                   }
    if (loop2>loop_max) {for(int i=0;i<NPIXELS;i++){track.setPixelColor(i, track.Color(255,0,0));}; track.show();
                                                    winner_fx();loop1=0;loop2=0;dist1=0;dist2=0;speed1=0;speed2=0;timestamp=0;
                                                    start_race();
                                                   }
    if ((millis() & 512)==(512*draworder)) {if (draworder==0) {draworder=1;}
                          else {draworder=0;}   
                         }; 

    if (draworder==0) {draw_car1();draw_car2();}
        else {draw_car2();draw_car1();}   
                 
    track.show(); 
    delay(tdelay);
    
    if (TBEEP>0) {TBEEP-=1; 
                  if (TBEEP==0) {noTone(PIN_AUDIO);}; // lib conflict !!!! interruption off by neopixel
                 };   
}

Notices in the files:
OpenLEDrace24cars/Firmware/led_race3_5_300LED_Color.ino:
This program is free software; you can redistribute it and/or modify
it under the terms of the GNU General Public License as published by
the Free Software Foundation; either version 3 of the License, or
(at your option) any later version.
